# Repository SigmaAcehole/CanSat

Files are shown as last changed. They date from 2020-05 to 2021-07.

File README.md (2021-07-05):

# CanSat
My Teensy code for CanSat using Arduino IDE.
My PCB schematics and design using AutoDesk Eagle.
This code fulfils the problem statement of CanSat 2020 organized by American Astronautical Society (AAS).

# Modules Used
1. Teensy 3.6 - Microcontroller board
2. MS5611 - Altitude/Pressure/Temperature
3. Adafruit Ultimate Breakout - GPS receiver
4. SPS30 - Dust Particle
5. MS4525DO - Air Speed
6. XBee S2C PRO - Telemetry

# PCB Design
|Board|Schematic|
|:---:|:---:|
|PCB|sche|

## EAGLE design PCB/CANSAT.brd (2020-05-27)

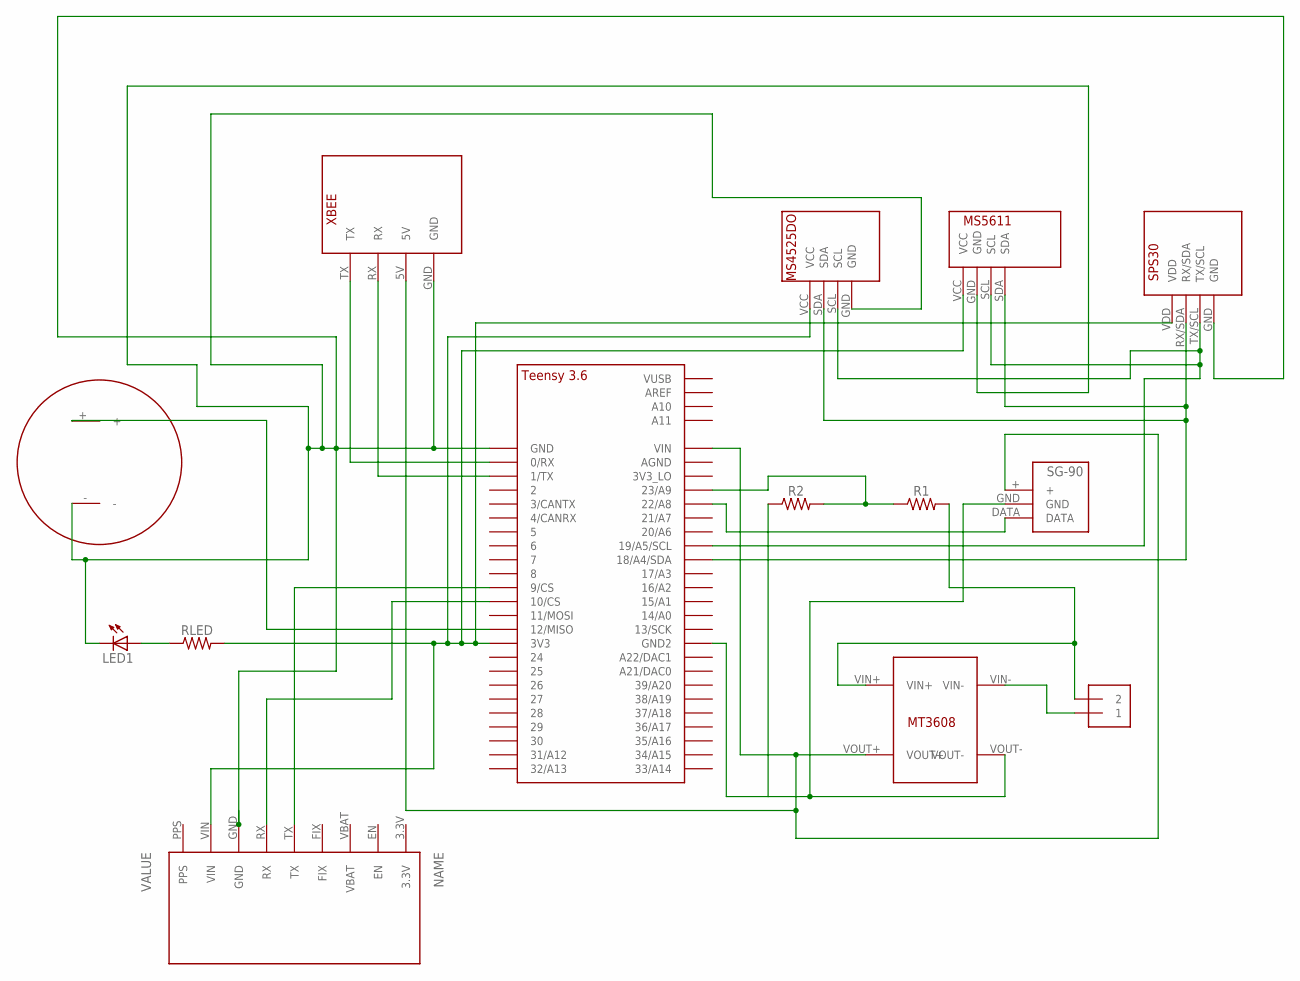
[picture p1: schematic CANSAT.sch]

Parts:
GPS1: ADAFRUITGPSBREAKOUT; ADAFRUITGPS
J1: 1X2-3.5MM
LED1: LED5MM
R1: 1.2K; AXIAL-0.3
R2: 2.5K; AXIAL-0.3
RLED: 220; AXIAL-0.3
U$1: MT3608
U$2: TEENSY_3.5/3.6_BASIC
U$3: XBEE-S2CPRO
U$4: MS4525DO
U$5: MS5611
U$6: SPS30
U$7: AL-3035; BUZZER
U$8: SG-90

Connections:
3V3: GPS1.VIN, RLED.P$2 (2), U$2.3V3, U$4.VCC, U$5.VCC, U$6.VDD
5V: U$1.VOUT+, U$2.VIN, U$3.5V, U$8.+
GND: GPS1.GND, LED1.K (C), U$2.GND, U$3.GND, U$4.GND, U$5.GND, U$6.GND, U$7.-
GND2: R2.P$1 (1), U$1.VOUT-, U$2.GND2, U$8.GND
unnamed: U$2.0/RX, U$3.TX
unnamed: LED1.A, RLED.P$1 (1)
unnamed: U$2.1/TX, U$3.RX
unnamed: J1.2, R1.P$2 (2), U$1.VIN+
unnamed: J1.1, U$1.VIN-
unnamed: U$2.22/A8, U$8.DATA
unnamed: U$2.12/MISO, U$7.+
unnamed: GPS1.TX, U$2.9/CS
unnamed: R1.P$1 (1), R2.P$2 (2), U$2.23/A9
unnamed: GPS1.RX, U$2.10/CS
SCL: U$2.19/A5/SCL, U$4.SCL, U$5.SCL, U$6.TX/SCL
SDA: U$2.18/A4/SDA, U$4.SDA, U$5.SDA, U$6.RX/SDA

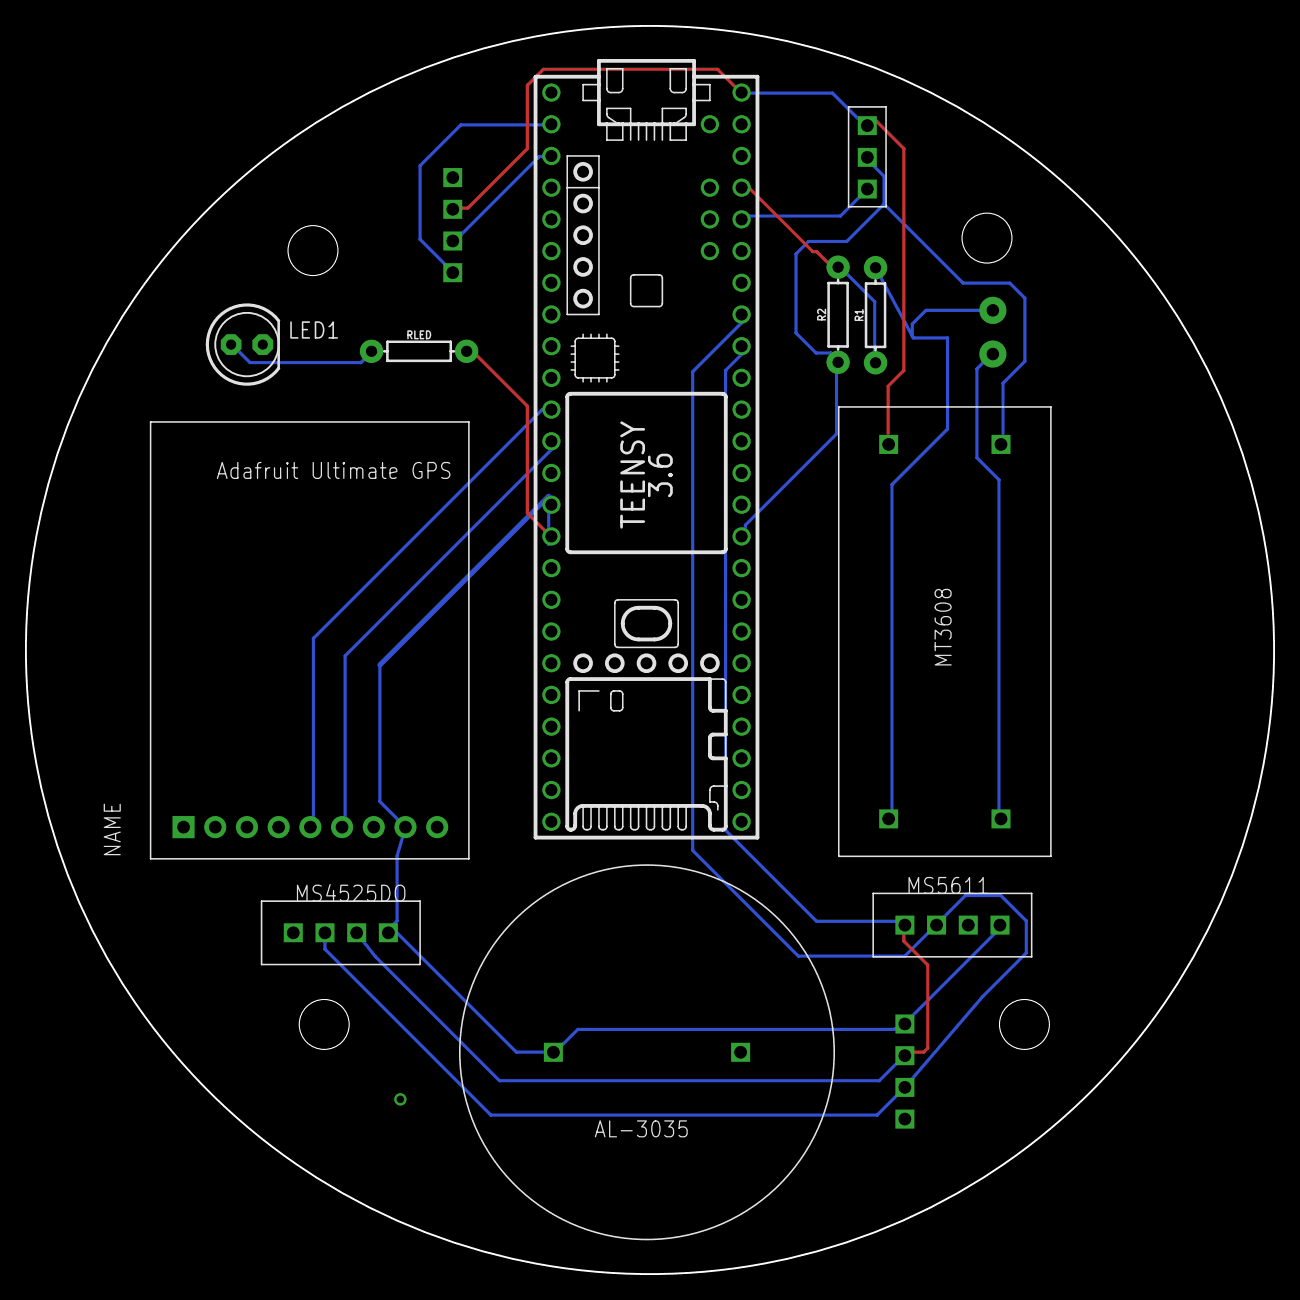
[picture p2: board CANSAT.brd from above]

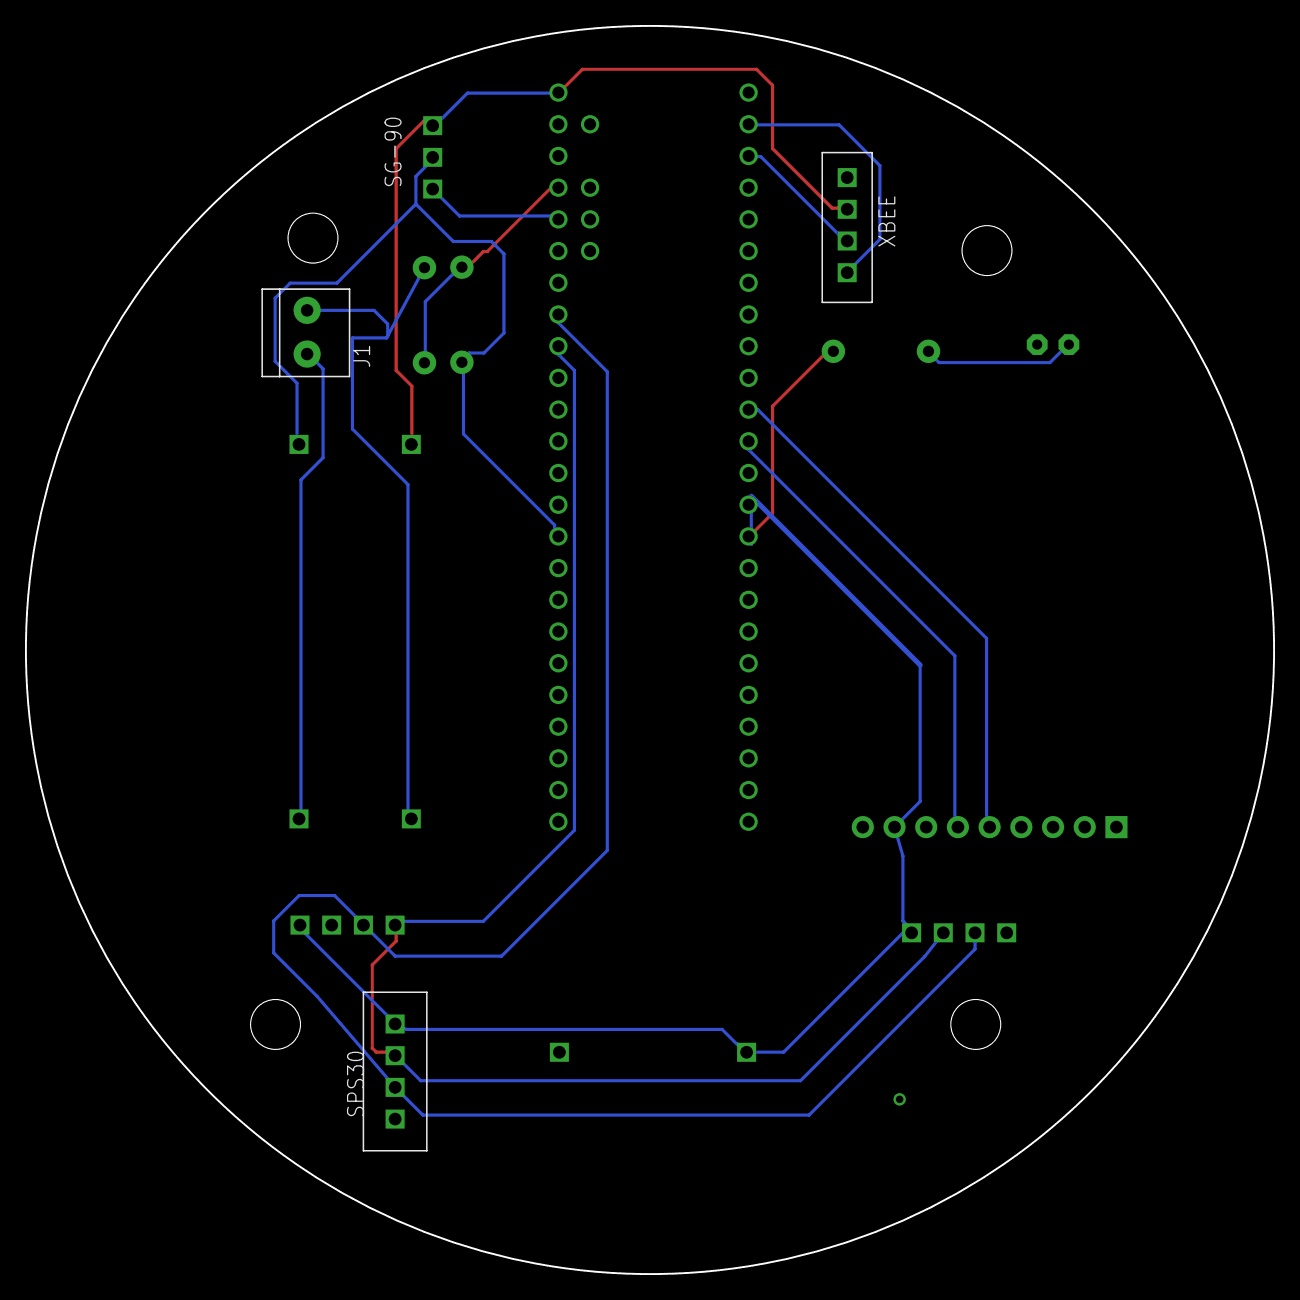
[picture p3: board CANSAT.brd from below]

Board: 2 copper layers, 100.0 x 100.0 mm, 14 parts (4 on the bottom side), 16 nets.

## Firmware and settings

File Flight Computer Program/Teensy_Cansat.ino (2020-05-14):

#include <EEPROM.h>   
#include<Wire.h>
#include<SoftwareSerial.h>
#include<XBee.h>
#include<printf_Teensy.h>
#include<sps30_Teensy.h>
#include<TinyGPS.h>
#include<Servo.h>
#include<SD.h>


XBee xbee = XBee();
SPS30 sps30;
TinyGPS gps;
Servo servo;

#define gpsPort Serial3
#define AirSpeedAddress 0x28         //For MS4525DO
#define BarometerAddress 0x77        //For MS5611
#define SP30_COMMS SERIALPORT2       //For SPS30
#define TX_PIN 10                        
#define RX_PIN 9                         

int LED=11;
int BUZZER=12;
float VOLSENSE=23;
int PacketCount0;
int count;
int state0;
int t1,t2;

int SAVE[6];    //array to store calibration data

struct sps_values val;    //SPS30 OUTPUT

int C1,C2,C3,C4,C5,C6,DT,DP,dT,P,pressure;   //constants related to altimeter



byte fetch_pressure(unsigned int *p_Pressure);  // For airspeed sensor
unsigned int P_dat;
unsigned int T_dat;
double PR,TR,V,VV;


static void smartdelay(unsigned long ms);    //For GPS
static void print_float(float val, float invalid, int len, int prec);
static void print_int(unsigned long val, unsigned long invalid, int len);
static void print_date(TinyGPS &gps);
static void print_str(const char *str, int len);
float flat, flon;
  
const String TEAMID = "TEAM B";
String SOFTWARESTATE="";
int HOUR,MINUTE,SECOND;
String GPSTIME;
float PRESSURE,TEMPERATURE,ALTITUDE,PARTICLECOUNT,VOLTAGE,AIRSPEED,GPSLATITUDE,GPSLONGITUDE,GPSALTITUDE,GPSSATS;
int PACKETCOUNT,MISSIONTIME; 

String TELEMETRYPACKAGE;

void setup()
{
  Wire.begin();
  Serial.begin(9600);
  Serial1.begin(9600);
  Serial2.begin(9600);
  gpsPort.begin(9600);
  servo.attach(6);

  delay(10);
  
  xbee.setSerial(Serial1);
  sps30.SetSerialPin(RX_PIN,TX_PIN);
  sps30.start();
  
  

  delay(50);

  pinMode(BUZZER,OUTPUT);
  pinMode(LED,OUTPUT);
  digitalWrite(LED,HIGH);
  delay(5000);
  digitalWrite(LED,LOW);

  
}

void loop()
{
  C1=EEPROM.read(0);
  C2=EEPROM.read(1);
  C3=EEPROM.read(2);
  C4=EEPROM.read(3);
  C5=EEPROM.read(4);
  C6=EEPROM.read(5);
  
  PRESSURE= getPressure();   // in Pa
  TEMPERATURE= getTemperature();  // in C
  ALTITUDE= getAltitude();   // in m
  PARTICLECOUNT= getParticle();  //in mg/m^3
  VOLTAGE= getVoltage();    // in V
  AIRSPEED= getAirspeed();  // in m/s
  GPSSATS= (gps.satellites(), TinyGPS::GPS_INVALID_SATELLITES, 5);
  GPSALTITUDE=(gps.f_altitude(), TinyGPS::GPS_INVALID_F_ALTITUDE, 7, 2);
  GPSLATITUDE=(flat, TinyGPS::GPS_INVALID_F_ANGLE, 10, 6);
  GPSLONGITUDE=(flon, TinyGPS::GPS_INVALID_F_ANGLE, 11, 6);
  GPSTIME=String(HOUR)+":"+String(MINUTE)+":"+String(SECOND);    //in HH:MM:SS
  

  float RefHeight = 213.36;     //in coordinates 12°58'32.2"N 79°09'38.3"E

  float RefAlt= GPSALTITUDE-RefHeight;

  //Software state
  count=EEPROM.read(8);
  if(RefAlt<3)
  {
    SOFTWARESTATE="GROUND OPERATION";
  }
  else if(RefAlt > 450 && count==0)
  {
    count++;
    EEPROM.write(8,count);
  }
  else if (RefAlt<450 && RefAlt>110 && count==1)
  {
    SOFTWARESTATE="GLIDING";
  }
  else if(RefAlt<110 && count==1)
  {
    SOFTWARESTATE="LANDING";
  }
  else
  {
    SOFTWARESTATE="ASCENDING";
  }
/////MISSIONTIME/////
  state=EEPROM.read(6);
  if(state==0)
  {
    t1=SECOND;
    state++;
    EEPROM.write(6,state);
  }
  if(state==1)
  {
    t2=SECOND;
  }
  MISSIONTIME= t2-t1;

  PacketCount=EEPROM.read(7);
  PACKETCOUNT=PacketCount;

  TELEMETRYPACKAGE= TEAMID + "," + String(MISSIONTIME) + "," + String(PACKETCOUNT) + "," + String(ALTITUDE) + "," + String(PRESSURE) + "," + String(TEMPERATURE) + "," + 
                    String(VOLTAGE) + "," + String(GPSTIME) + "," + String(GPSLATITUDE) + "," + String(GPSLONGITUDE) + "," + String(GPSALTITUDE) + "," + String(GPSSATS) 
                    + "," + String(AIRSPEED) + "," + SOFTWARESTATE + "," + String(PARTICLECOUNT);
  PacketCount++;
  EEPROM.write(7,PacketCount);

  Serial1.println(TELEMETRYPACKAGE);   //Send Telemetry package to GCS
  delay(1000);

 File dataFile = SD.open("datalog.txt", FILE_WRITE);
 //SD card datalogging
  if (dataFile) {
    dataFile.println(TELEMETRYPACKAGE);
    dataFile.close();
  }

  if(RefAlt<20 && count==1)     //Ring buzzer 
  {
    digitalWrite(BUZZER,HIGH);
  }

  if(RefAlt < 450 && RefAlt > 400 && count==1)       //Payload deployment
  {
    servo.write(60);
  }
  if(RefAlt<100 && count==1)       //Second parachute deployment
  {
    servo.write(120);
  }
  

if(Serial1.available()==true)  // Check if commmand sent from GCS
{
  char C=Serial1.read();
  if(C=='c')
  BarometerCalibration();
}
 
}

///////////FUNCTION FOR ALTIMETER//////////////

void DigitalPressure()  //get ADC converted value of pressure
{
  Wire.beginTransmission(BarometerAddress);
  Wire.write(0x00);
  Wire.write(0x48);   //commanding ADC for pressure conversion
  Wire.endTransmission();
  delay(2);
  Wire.requestFrom(BarometerAddress,2);
  int DP=Wire.read();
  
}

void DigitalTemperature()  //get ADC converted value of temperature
{
  Wire.beginTransmission(BarometerAddress);
  Wire.write(0x00);
  Wire.write(0x58);   //commanding ADC for temperature conversion 
  Wire.endTransmission();
  delay(2);
  Wire.requestFrom(BarometerAddress,2);
  DT=Wire.read();
  
}

void BarometerCalibration()    // Calibrate Altimeter and Read caliberation data
{
  Wire.beginTransmission(BarometerAddress);
  Wire.write(0x1E);    //Resets caliberation data
  Wire.endTransmission();
  
  Wire.beginTransmission(BarometerAddress);
  Wire.write(1);    
  Wire.endTransmission();
  Wire.requestFrom(BarometerAddress,1);
  C1=Wire.read();

  Wire.beginTransmission(BarometerAddress);
  Wire.write(2);    
  Wire.endTransmission();
  Wire.requestFrom(BarometerAddress,1);
  C2=Wire.read();

  Wire.beginTransmission(BarometerAddress);
  Wire.write(3);    
  Wire.endTransmission();
  Wire.requestFrom(BarometerAddress,1);
  C3=Wire.read();

  Wire.beginTransmission(BarometerAddress);
  Wire.write(4);   
  Wire.endTransmission();
  Wire.requestFrom(BarometerAddress,1);
  C4=Wire.read();

  Wire.beginTransmission(BarometerAddress);
  Wire.write(5);   
  Wire.endTransmission();
  Wire.requestFrom(BarometerAddress,1);
  C5=Wire.read();

  
  Wire.beginTransmission(BarometerAddress);
  Wire.write(6);    
  Wire.endTransmission();
  Wire.requestFrom(BarometerAddress,1);
  C6=Wire.read();

  int SAVE[6]={C1,C2,C3,C4,C5,C6};
  for(int i=0;i<6;i++)
  EEPROM.write(i,SAVE[i]);  
}

float getTemperature()  //get actual temperature
{ 
  DigitalTemperature();
  dT= DT- C5*pow(2,8);
  int TEMP= 2000+dT*C6/pow(2,23);
  float temperature= TEMP/100;
  return temperature;      //Temperature= TEMP/100 C
}

float getPressure()  //get actual temperature compensated pressure
{
  DigitalPressure();
  int oFF= C2*pow(2,16)+(C4*dT)/pow(2,7);
  int SENS=C1*pow(2,15)+(C3*dT)/pow(2,5);
  P=(DP*SENS/pow(2,21) - oFF)/pow(2,15);
  float pressure=100000*P/100;
  return pressure;     // Pressure= P/100 hPa
}

float getAltitude()    // get Altitude from ground
{
  float Altitude= (1-pow((P/101325),0.190284))*44307.694;   // in meters
  return Altitude;
}

/////////////FUNCTION FOR DUST PARTICLE SENSOR/////////////

float getParticle()
{
   sps30.GetValues(&val);
   float PM10= 1000*val.NumPM10;
   return PM10;
}

//////////////FUNCTION FOR VOLTAGE SENSOR/////////////

float getVoltage()
{
  int val= analogRead(23);
  float vol= map(val,0,1023,0,2.5);
  float voltage=37*vol/25;
  return voltage;
}

//////////////////FUNCTION FOR AIRSPEED SENSOR/////////////

float getAirspeed()
{
  byte  _status = fetch_pressure(&P_dat, &T_dat);
  PR = (double)((P_dat-819.15)/(14744.7)) ;
  PR = (PR - 0.49060678) ;
  PR = abs(PR);
  V = ((PR*13789.5144)/1.225);
  VV = (sqrt((V)));    //airspeed in m/s
  TR = (double)((T_dat*0.09770395701));
  TR = TR-50;

  return VV;
}

byte fetch_pressure(unsigned int *p_P_dat, unsigned int *p_T_dat)
{
  byte address, Press_H, Press_L, _status;
  unsigned int P_dat;
  unsigned int T_dat;

  Wire.beginTransmission(AirSpeedAddress);
  Wire.endTransmission();
  delay(100);

  Wire.requestFrom(AirSpeedAddress,4);
  Press_H = Wire.read();
  Press_L = Wire.read();
  byte Temp_H = Wire.read();
  byte  Temp_L = Wire.read();
  Wire.endTransmission();


  _status = (Press_H >> 6) & 0x03;
  Press_H = Press_H & 0x3f;
  P_dat = (((unsigned int)Press_H) << 8) | Press_L;
  *p_P_dat = P_dat;

  Temp_L = (Temp_L >> 5);
  T_dat = (((unsigned int)Temp_H) << 3) | Temp_L;
  *p_T_dat = T_dat;
  return (_status);
}

/////////////////////////////FUNCTION FOR GPS/////////////////////////////


static void smartdelay(unsigned long ms)   //To set frequency for GPS
{
  unsigned long start = millis();
  do {
    while (gpsPort.available())
      gps.encode(gpsPort.read());
  } while (millis() - start < ms);
}


static void print_date(TinyGPS &gps)
{
  int year;
  byte month, day, hour, minute, second, hundredths;
  unsigned long age;
  gps.crack_datetime(&year, &month, &day, &hour, &minute, &second, &hundredths, &age); 
  HOUR=hour;
  MINUTE=minute;
  SECOND=second;
  smartdelay(1000);
}

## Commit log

2020-05-27 Add files via upload
    Contains weight, power consumed and dimensions of major electronics used.
    [PowerBudget.xlsx]
2021-07-05 final update
    [CANSAT.brd, CANSAT.sch]

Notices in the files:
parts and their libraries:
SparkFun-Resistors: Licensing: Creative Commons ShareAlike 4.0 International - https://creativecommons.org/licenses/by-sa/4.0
